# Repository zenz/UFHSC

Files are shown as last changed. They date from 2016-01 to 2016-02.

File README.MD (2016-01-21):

准备开源一个东西，用来控制地暖系统的。
市场上有类似的产品，但都是闭源的，这个开源，爱折腾爱研究爱写程序的，可以通过这个东西来设计和测试自己的地暖控制逻辑。

包含的接口有：
1、两路温度传感器接口（用B=3950，100K 精度1% NTC电阻温度传感器）
2、一路壁挂炉采暖启停控制接口
3、一路循环泵启停控制接口
4、一路负载式温控面板接口
5、一路温控面板直接控制的热电阀接口
6、一个UART通讯接口，用于通过USB2TTL接线实现与电脑串口通讯
7、一个ICSP接口，用于给单片机刷写Bootloader
8、一个ESP-05款无线WIFI模块接口，用于实现IoT监控
9、一个USB/AC供电跳针接口，用于选择单片机电源供给方式，调试用
10、一个预留的开关判断接口（目前在代码中用于是否连接循环泵的判断）

整个设备，全部采用直插式原件，方便爱好者自己焊接制作。所有用到的零件，都可以在网上（淘宝）购买到。
温度传感器精度可通过选择精度高的NTC电阻以及分压电阻(4.7K)来调节。
目前选用的NTC精度1%，分压电阻精度5%，测试下来在测试物温度恒定时，波动温度不超过0.2度（个人认为对地暖来说这个精度够了，波动更大的原因是开关电源的稳定性）。

单片机采用ATMEL公司的ATMEGA328P-PU，8位处理芯片，FLASH内存32K，动态内存2K，刷开源固件Arduino。
原始控制代码也全部开源，用Arduino编写，在Arduino IDE 1.0.5 以上版本编译通过并可通过USB2TTL上传到单片机。

开源的目的是什么？
个人一直是开源（软硬件）的支持者，认同开源可以使得在开放式讨论环境中，目标理论和算法能够得到更充分的探讨和完善。而且能够在使用环境适应性上有更加灵活的应对方法来解决实际的问题。FDM（熔融堆积成型）三维打印机这几年的发展就是一个例子。还有桌面CNC铣床GBRL，微型纺织机FirePicker等等。Github上随便搜搜都能找到一堆的开源软硬件项目。

开源会不会对企业带来经济损失？
个人认为这是一个伪命题。一个企业的研发能力是有限的，特别是中小型企业，要能够有人员和资金持续地，不断投入一个项目的研究还不钻牛角尖是很难的。因此，很多的企业，甚至是大企业，都采取部分开源的做法，来吸引更多对此问题关注的人参与进来，从而在获得的研究结果中提取有利于企业本身的数据和技术，来不断完善企业自己生产和销售的产品。产品做好了，买来使用的人其实占据了绝大多数。

开源需要的是什么？
开源需要的是真诚的交流和主动改变的心态，在这一点上，国外的开发者似乎比国内的做的要好一些。但这几年，国内的开源项目也多起来了。主要还是心态的慢慢转变吧。

接下来会怎么做？
我会把这个项目放到Github上，所有的设计文件，代码，让有想法又愿意分享并贡献的人可以跟进交流。希望这个开源项目能获得更多人的关注，从而使得对地面辐射采暖节能控制更多的了解和应用。这样我就成功了。如果最后也没有什么进步，那么我也至少努力过了。

OK，我要说的说完了。你约不约？

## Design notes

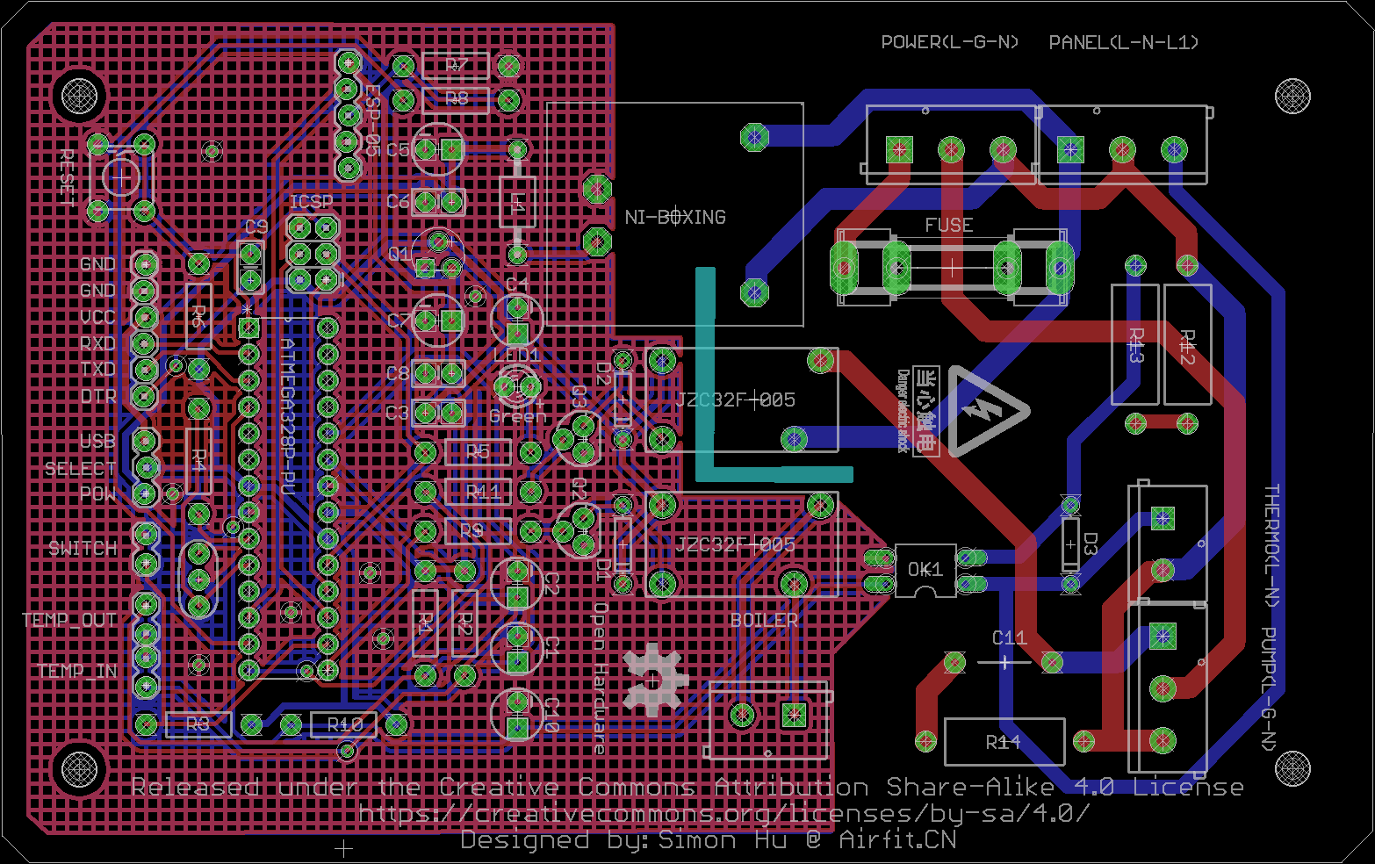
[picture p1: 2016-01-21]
PCB.png

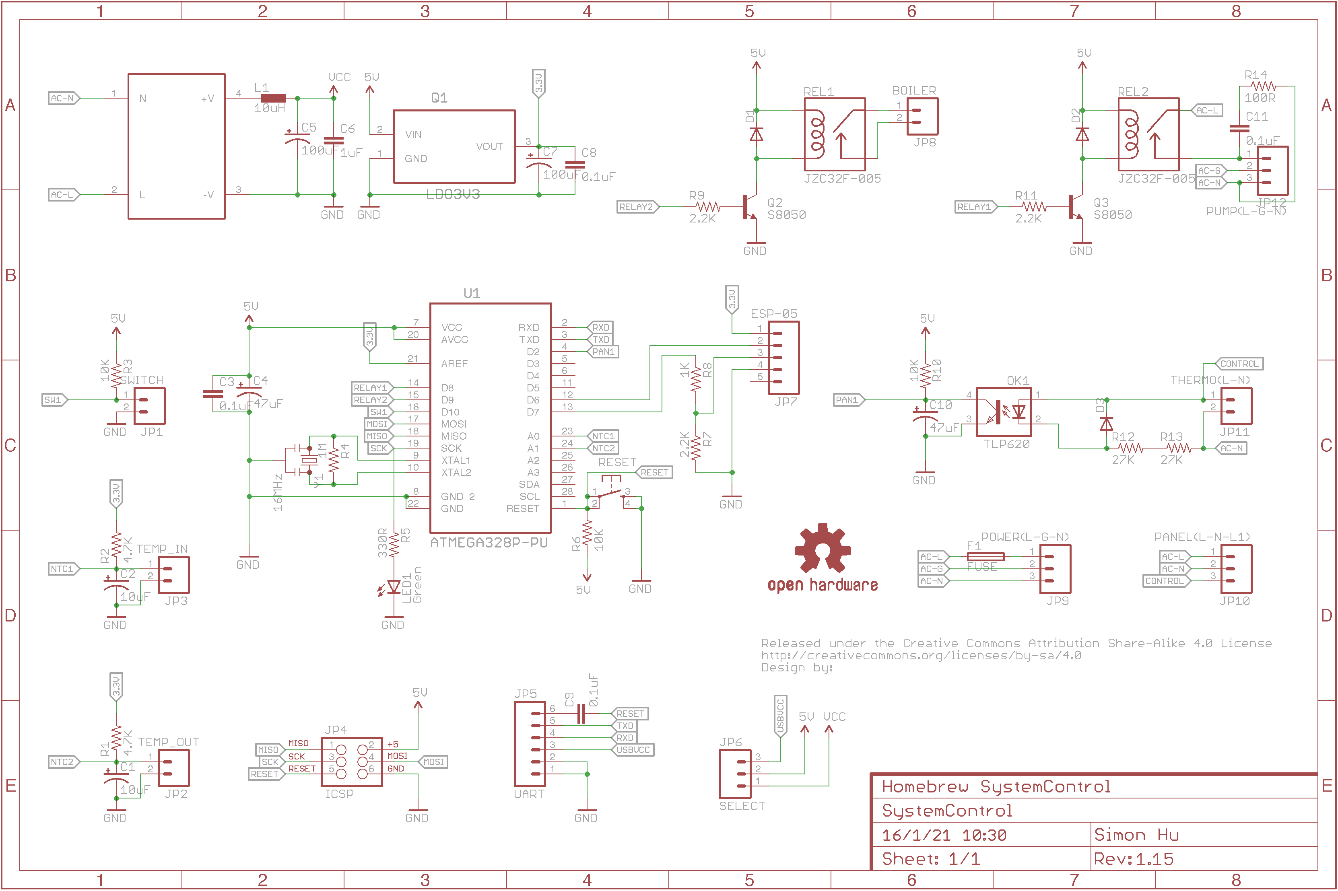
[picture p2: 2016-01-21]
SCH.png

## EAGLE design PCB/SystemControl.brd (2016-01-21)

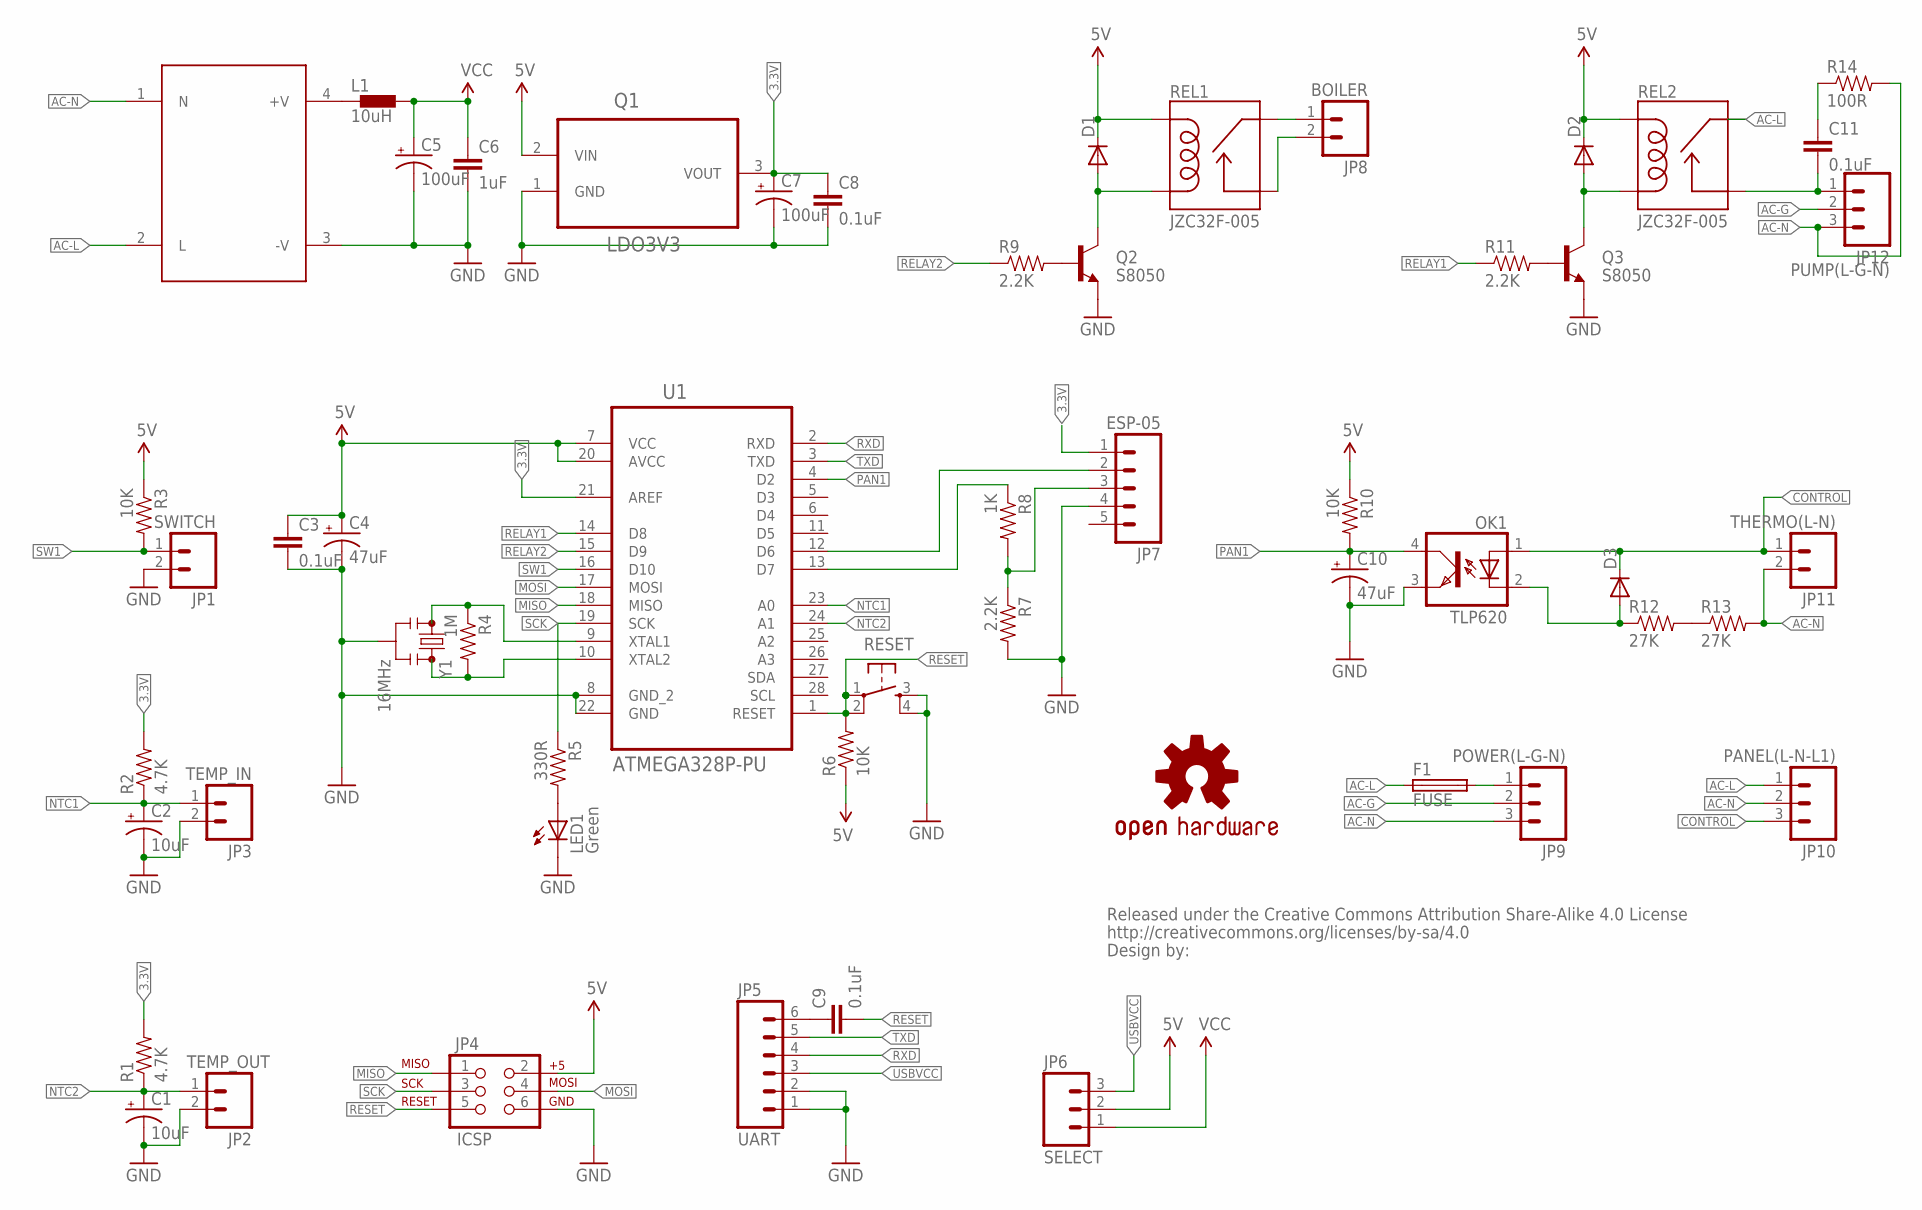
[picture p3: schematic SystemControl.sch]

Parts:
C1, C2: 10uF; CPOL-RADIAL-10UF-25V
C3, C8, C9: 0.1uF; CAP-PTH-SMALL2
C4, C10: 47uF; CPOL-RADIAL-10UF-25V
C5, C7: 100uF; CPOL-RADIAL-10UF-25V
C6: 1uF; CAP-PTH-SMALL2
C11: 0.1uF; CAP-PTH-LARGE
CC_TEXT1: CREATIVE_COMMONS
D1, D2, D3: 1N4007; DO-1N4148
F1: FUSE; SHK20L
IC1: NI-BOXING
JP1: SWITCH; 1X02_LOCK
JP2: TEMP_OUT; 1X02_LOCK
JP3: TEMP_IN; 1X02_LOCK
JP4: ICSP; 2X3
JP5: UART; 1X06_LOCK
JP6: SELECT; 1X03_LOCK
JP7: ESP-05; 1X05_LOCK
JP8: BOILER; SCREWTERMINAL-5MM-2
JP9: POWER(L-G-N); SCREWTERMINAL-5MM-3
JP10: PANEL(L-N-L1); SCREWTERMINAL-5MM-3
JP11: THERMO(L-N); SCREWTERMINAL-5MM-2
JP12: PUMP(L-G-N); SCREWTERMINAL-5MM-3
L1: 10uH; BL01RN1A
LED1: Green; LED3MM
LOGO1: OSHW-LOGOL; OSHW-LOGO-L
OK1: TLP620; DIL04
Q1: LDO3V3; TO127P254X533-3
Q2, Q3: S8050; TO-92
R1, R2: 4.7K; AXIAL-0.4
R3, R6, R10: 10K; AXIAL-0.4
R4: 1M; AXIAL-0.4
R5: 330R; AXIAL-0.4
R7, R9, R11: 2.2K; AXIAL-0.4
R8: 1K; AXIAL-0.4
R12, R13: 27K; AXIAL-0.6
R14: 100R; AXIAL-0.6
REL1, REL2: JZC32F-005; RELAY-JZC
RESET: TAC_SWITCHPTH; TACTILE-PTH
U1: ATMEGA328P-PU; DIP254P762X457-28
Y1: 16MHz; RESONATOR-PTH

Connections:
3.3V: C7.1 (+), C8.1, JP7.1, Q1.3 (VOUT), R1.P$2 (2), R2.P$2 (2), U1.21 (AREF)
5V: C3.1, C4.1 (+), D1.C, D2.C, JP4.2 (VCC), JP6.2, Q1.2 (VIN), R3.P$1 (1), R6.P$1 (1), R10.P$1 (1), REL1.5 (COIL1), REL2.5 (COIL1), U1.7 (VCC), U1.20 (AVCC)
AC-G: JP9.2, JP12.2
AC-L: F1.1A (1), IC1.2 (L), JP10.1, REL2.4 (MAIN)
AC-N: IC1.1 (N), JP9.3, JP10.2, JP11.2, JP12.3, R13.P$2 (2), R14.P$2 (2)
CONTROL: D3.C, JP10.3, JP11.1, OK1.1 (A)
GND: C1.2 (-), C2.2 (-), C3.2, C4.2 (-), C5.2 (-), C6.2, C7.2 (-), C8.2, C10.2 (-), IC1.3 (-V), JP1.2, JP2.2, JP3.2, JP4.6 (GND), JP5.1 (GND), JP5.2 (EMPTY), JP7.4, LED1.K (C), OK1.3 (EMIT), Q1.1 (GND), Q2.1 (E), Q3.1 (E), R7.P$2 (2), RESET.3, RESET.4, U1.8 (GND_2), U1.22 (GND), Y1.2
MISO: JP4.1 (MISO), U1.18 (MISO)
MOSI: JP4.4 (MOSI), U1.17 (MOSI)
unnamed: C9.1, JP5.6 (RESET)
unnamed: R4.P$1 (1), U1.9 (XTAL1), Y1.1
unnamed: R4.P$2 (2), U1.10 (XTAL2), Y1.3
unnamed: Q3.2 (B), R11.P$2 (2)
unnamed: D2.A, Q3.3 (C), REL2.1 (COIL2)
unnamed: Q2.2 (B), R9.P$2 (2)
unnamed: D1.A, Q2.3 (C), REL1.1 (COIL2)
unnamed: JP8.1, REL1.4 (MAIN)
unnamed: JP8.2, REL1.3 (NO)
unnamed: LED1.A, R5.P$2 (2)
unnamed: C11.2, JP12.1, REL2.3 (NO)
unnamed: IC1.4 (+V), L1.1
unnamed: C11.1, R14.P$1 (1)
unnamed: JP7.3, R7.P$1 (1), R8.P$2 (2)
unnamed: F1.2A (2), JP9.1
unnamed: R12.P$2 (2), R13.P$1 (1)
unnamed: D3.A, OK1.2 (C), R12.P$1 (1)
unnamed: JP7.2, U1.12 (D6)
unnamed: R8.P$1 (1), U1.13 (D7)
NTC1: C2.1 (+), JP3.1, R2.P$1 (1), U1.23 (A0)
NTC2: C1.1 (+), JP2.1, R1.P$1 (1), U1.24 (A1)
PAN1: C10.1 (+), OK1.4 (COL), R10.P$2 (2), U1.4 (D2)
RELAY1: R11.P$1 (1), U1.14 (D8)
RELAY2: R9.P$1 (1), U1.15 (D9)
RESET: C9.2, JP4.5 (RESET), R6.P$2 (2), RESET.1, RESET.2, U1.1 (RESET)
RXD: JP5.4 (RXD), U1.2 (RXD)
SCK: JP4.3 (SCK), R5.P$1 (1), U1.19 (SCK)
SW1: JP1.1, R3.P$2 (2), U1.16 (D10)
TXD: JP5.5 (TXD), U1.3 (TXD)
USBVCC: JP5.3 (VCC), JP6.3
VCC: C5.1 (+), C6.1, JP6.1, L1.2

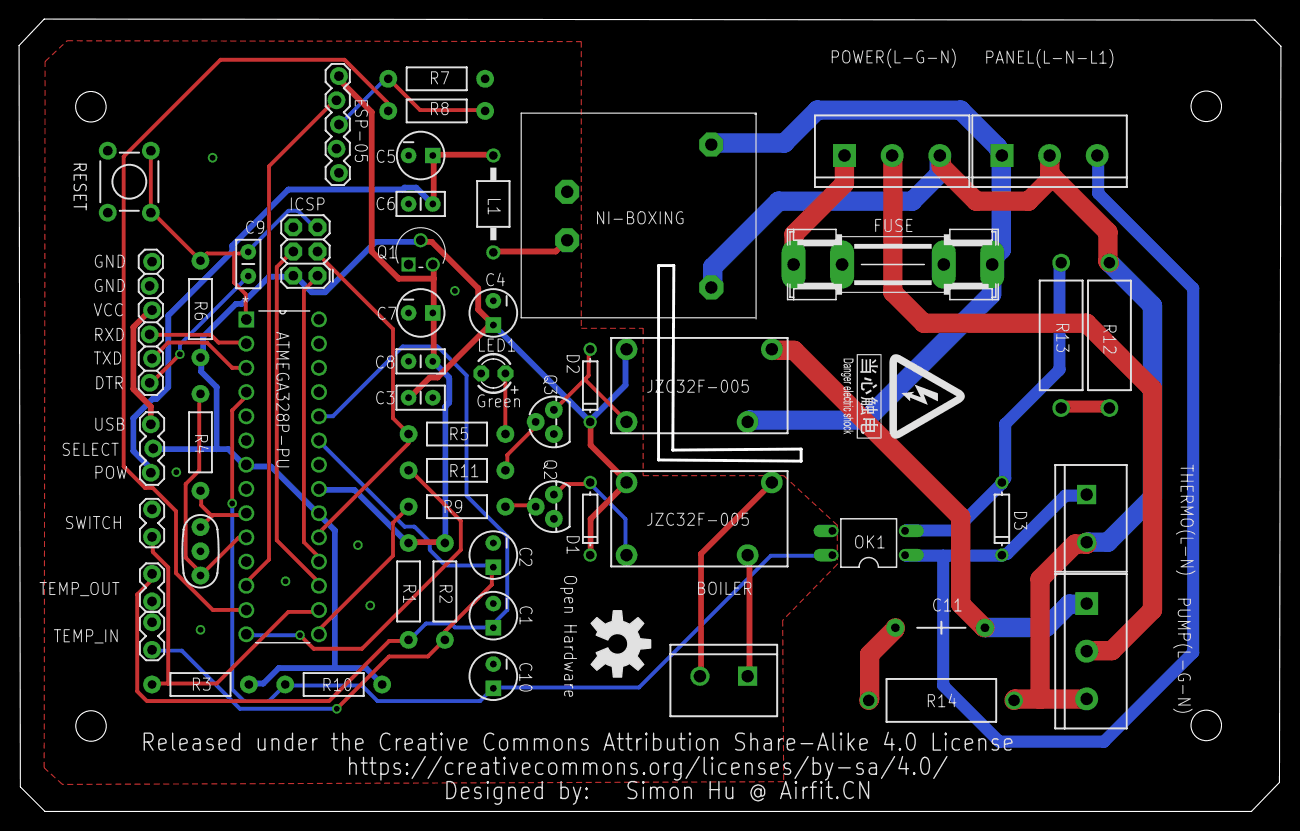
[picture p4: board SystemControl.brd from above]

Board: 2 copper layers, 132.3 x 83.1 mm, 55 parts (0 on the bottom side), 40 nets.

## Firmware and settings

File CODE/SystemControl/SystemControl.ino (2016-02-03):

#include "Boiler.h"
#include "Pump.h"
#include "Panel.h"
#include "Led.h"

#define WORKING_TEMP 30UL // 回水不30度
#define PROTECT_PERIOD 180000UL // 保护时间为3分钟
#define BLINK_INTERVAL_NORMAL 1000UL  // 供热时1秒一闪
#define BLINK_INTERVAL_SHORT 250UL  // 温度出错时1/4秒一闪
#define BLINK_INTERVAL_LONG 3000UL  // 非供热时3秒一闪
#define DISPLAY_INTERVAL 1000UL // 显示间隔1秒
#define UPDATE_INTERVAL 300000UL  // 更新服务间隔5分钟
#define PROCESSING_PLOT // 输出Processing程序监控数据
#define WATCHDOG  // 使用看门狗
//#define DIGITAL_TUBE  // 使用4位数字管
//#define ESPWIFI // 如果开启了ESPWIFI,则会自动关闭PROCESSING_PLOT及WATCHDOG
//#define DEBUG // 允许串口输出调试

#if defined(DIGITAL_TUBE) || defined(ESPWIFI) || defined(PROCESSING_PLOT)
#include "Thread.h"
#include "ThreadController.h"
ThreadController controll = ThreadController();
#endif

#ifdef WATCHDOG
#include <avr/wdt.h>
#endif

#ifdef DIGITAL_TUBE
// 用数字管显示进回水温度
#include "TM1637.h"
#define CLK 11
#define DIO 12
TM1637 tm1637(CLK, DIO);
boolean tmPowerOn = false;
#endif

#if defined(PROCESSING_PLOT) || defined(DIGITAL_TUBE)
Thread* displayThread = new Thread();
#endif

#ifdef ESPWIFI
#undef PROCESSING_PLOT
#undef WATCHDOG
#include "SoftwareSerial.h"
SoftwareSerial Serial1(6, 7); // RX, TX
#include "WiFiEsp.h"

#define ROUTER_SSID "ROUTER" // 路由
#define ROUTER_PASS "PASSWORD" // 密码
#define SERVER "api.yeelink.net"
#define YEELINKAPI  "YOURYEELINKAPI"
#define DEVICEID  344501
#define SENSORID1 382953  // 回水温度
#define SENSORID2 382954  // 进水温度
#define SENSORID3 382955  // 壁挂炉
#define SENSORID4 382956  // 循环泵
#define SENSORID5 382957  // 温控器
int status = WL_IDLE_STATUS;
WiFiEspClient wifiClient;
boolean wifiReady = true;
Thread* updateThread = new Thread();
#endif

// 工作灯
uint8_t pinLed = 13;
// 两个温度传感器
uint8_t pinTempOut = A0, pinTempIn = A1;
// 温控面板
uint8_t pinPanel = 2;
// 壁挂炉采暖控制
uint8_t pinBoiler = 9;
// 循环泵控制
uint8_t pinPump = 8;
uint8_t pinPumpReady = 10;
bool pumpReady;

// 初始化各个类
Led led(pinLed);
Thermistor thermistorIn(pinTempIn);
Thermistor thermistorOut(pinTempOut);
Panel panel(pinPanel);
Boiler boiler;
Pump pump;

// 定义用到的公共变量
uint32_t boilerProtectPeriod, pumpProtectPeriod;
bool panelState = false, boilerState = false, pumpState = false;

//--------------------------------------------------------------------
// 系统初始化
//--------------------------------------------------------------------

void setup() {
#if defined(PROCESSING_PLOT) || defined(ESPWIFI) || defined(DEBUG)
  Serial.begin(9600);
#endif
  analogReference(EXTERNAL);
  pinMode(pinBoiler, OUTPUT); // 输出模式必须显性指定
  pinMode(pinPump, OUTPUT); // 输出模式必须显性指定
  pinMode(pinLed, OUTPUT);

  boiler.setTargetTemperature(WORKING_TEMP);
  boiler.setProtectPeriod(PROTECT_PERIOD);
  pump.setProtectPeriod(PROTECT_PERIOD);
  pumpReady = !digitalRead(pinPumpReady);

#ifdef DIGITAL_TUBE
  tm1637.init(); // 数字管初始化
  tm1637.set(BRIGHT_TYPICAL); // 普通亮度
  tm1637.display(0, 0); // 未进入循环处理程序前,4位全部显示0
  tm1637.display(1, 0);
  tm1637.display(2, 0);
  tm1637.display(3, 0);
#endif

#if defined(DIGITAL_TUBE) || defined(PROCESSING_PLOT)
  displayThread->onRun(displayCallback);
  displayThread->setInterval(DISPLAY_INTERVAL);
  controll.add(displayThread);
#endif

#ifdef ESPWIFI
  // 初始化ESP模块
  Serial1.begin(9600);
  WiFi.init(&Serial1);

  if (WiFi.status() == WL_NO_SHIELD) { // 没有发现ESPwifi模块
    Serial.println("ESP Wifi shield not present");
    wifiReady = false;
  }

  if (wifiReady) {
    while (status != WL_CONNECTED) {
      status = WiFi.begin(ROUTER_SSID, ROUTER_PASS);
    }
    Serial.println("Connected to the network");
    printWifiStatus();
  }

  updateThread->onRun(updateCallback);
  updateThread->setInterval(UPDATE_INTERVAL);
  controll.add(updateThread);
#endif

#ifdef WATCHDOG
  wdt_enable(WDTO_500MS); // 500毫秒无响应视为死机,重新启动. 如果用了Yeelink服务,则应该有更长时间.
#endif
}

//--------------------------------------------------------------------
// 主体循环
//--------------------------------------------------------------------

void loop() {
  panel.update(); // 更新面板状态
  panelState = panel.getState(); // 读取面板状态
  panelState = true; // 测试时强制为导通状态
  if (!panelState) {
    // 如果温控面板关闭了,那么无需壁挂炉启动,泵也应该停止
    led.setBlinkInterval(BLINK_INTERVAL_LONG); // 闪灯频率降到每3秒一次.
    boiler.setTargetTemperature(0);
    boilerState = boiler.update();
    if (pumpReady) { // 有泵,需要进行相应处理
      pump.disable();
      pumpState = pump.update();
    } else {
      pumpState = false;
    }
  } else { // 如果温控面板没有关闭
    led.setBlinkInterval(BLINK_INTERVAL_NORMAL); // 闪灯频率变为1秒一次
    boiler.setTargetTemperature(WORKING_TEMP);
    boilerState = boiler.update();
    if (pumpReady) { // 有泵,需要进行相应处理
      pump.allow();
      pumpState = pump.update();
    } else {
      pumpState = false;
    }
  }
  // 如果温度不正确,闪灯频率变为0.2秒一次
  if (boiler.getTemperatureIn() == -27 || boiler.getTemperatureOut() == -27) {
    led.setBlinkInterval(BLINK_INTERVAL_SHORT);
  }

  led.blink(); // 更新闪灯状态

#if defined(DIGITAL_TUBE) || defined(ESPWIFI) || defined(PROCESSING_PLOT)
  controll.run();
#endif

#ifdef WATCHDOG
  wdt_reset(); // 喂狗,防止重启
#endif
}

//--------------------------------------------------------------------
// 显示功能
//--------------------------------------------------------------------

#if defined(PROCESSING_PLOT) || defined(DIGITAL_TUBE)
void displayCallback() {
#ifdef PROCESSING_PLOT
  Serial.print(boiler.getTemperatureOut());
  Serial.print(",");
  Serial.print(boiler.getTemperatureIn());
  Serial.print(",");
  Serial.print(pumpState);
  Serial.print(",");
  Serial.println(boilerState);
#endif

#ifdef DIGITAL_TUBE
  tm1637.display(0, byte(round(boiler.getTemperatureOut())) / 10);  // 壁挂炉出水温度十位
  tm1637.display(1, byte(round(boiler.getTemperatureOut())) % 10);  // 壁挂炉出水温度个位
  tm1637.display(2, byte(round(boiler.getTemperatureIn())) / 10);   // 壁挂炉回水温度十位
  tm1637.display(3, byte(round(boiler.getTemperatureIn())) % 10);   // 壁挂炉回水温度各位
  tm1637.point(tmPowerOn); // 显示分割符号
  tmPowerOn = !tmPowerOn; // 实现分隔符闪烁
#endif
}
#endif

//--------------------------------------------------------------------
// 网络数据更新功能
//--------------------------------------------------------------------

#ifdef ESPWIFI
void updateCallback() {
  // 面板状态
  Serial.println("update panelState");
  postData(panelState, YEELINKAPI, DEVICEID, SENSORID5);

  // 循环本状态
  Serial.println("update pumpState");
  postData(pumpState, YEELINKAPI, DEVICEID, SENSORID4);

  // 壁挂炉状态
  Serial.println("update boilerState");
  postData(boilerState, YEELINKAPI, DEVICEID, SENSORID3);

  // 出水温度
  Serial.print("Send Output temperature: ");
  Serial.println(boiler.getTemperatureOut());
  postData(round(boiler.getTemperatureOut()), YEELINKAPI, DEVICEID, SENSORID1);

  // 回水温度
  Serial.print("Send Input temperature: ");
  Serial.println(boiler.getTemperatureIn());
  postData(round(boiler.getTemperatureIn()), YEELINKAPI, DEVICEID, SENSORID2);

  Serial.println("Update finished!");
}

void printWifiStatus()
{
  // 显示连接到的SSID
  Serial.print("SSID: ");
  Serial.println(WiFi.SSID());

  // 显示获取的IP地址
  IPAddress ip = WiFi.localIP();
  Serial.print("IP Address: ");
  Serial.println(ip);

  // 显示接受信号强度
  long rssi = WiFi.RSSI();
  Serial.print("Signal strength (RSSI):");
  Serial.print(rssi);
  Serial.println(" dBm");
}

void postData(int data, String apikey, unsigned long deviceid, unsigned long sensorid)
{
  if (wifiClient.connect(SERVER, 80)) {
    Serial.println("Connected to server!");
    Serial.println("Send data now.");
    int thisLength = 10 + getLength(data);

    wifiClient.print("POST /v1.0/device/");
    wifiClient.print(deviceid);
    wifiClient.print("/sensor/");
    wifiClient.print(sensorid);
    wifiClient.print("/datapoints HTTP/1.1\r\nHost: api.yeelink.net\r\n");
    wifiClient.print("Accept: */*\r\nU-ApiKey:");
    wifiClient.print(apikey);
    wifiClient.print("\r\nContent-Length: ");
    wifiClient.print(thisLength);
    wifiClient.print("\r\nContent-Type: application/x-www-form-urlencoded\r\n");
    wifiClient.print("Connection: close\r\n\r\n");
    wifiClient.print("{\"value\":");
    wifiClient.print(data);
    wifiClient.print("}");
    wifiClient.stop();

  } else {
    Serial.println("Connecting failure");
    Serial.println("Send data abort.");
    wifiClient.stop();
  }
}

int getLength(int someValue) {
  int digits = 1;
  int dividend = someValue / 10;

  while (dividend > 0) {
    dividend = dividend / 10;
    digits++;
  }
  return digits;
}
#endif

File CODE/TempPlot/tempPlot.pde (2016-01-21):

import processing.serial.*;

PFont f;
PFont F;
Serial myPort;        // The serial port
int xPos = 40;         // horizontal position of the graph

void setup () {
  // set the window size:  and Font size
  f = createFont("Arial", 12, true);
  F = createFont("Arial", 24, true);
  size(1024, 600);

  // List all the available serial ports
  //println(Serial.list());
  myPort = new Serial(this, "/dev/tty.SLAB_USBtoUART", 9600);
  myPort.bufferUntil('\n');
  // set inital background:
  background(100);
}
void draw () 
{
  String inputString, inString, outString, pumpString, boilerString;
  // everything happens in the serialEvent()
  if (myPort.available()>0) {
    // get the ASCII string:
    inputString = myPort.readStringUntil('\n');
    inString ="";
    if (inputString != null) {
      // trim off any whitespace:
      String[] temp = splitTokens(inputString, ",");
      print("State: ");
      print(inputString);
      if (temp[0] !=null) {
        outString = trim(temp[0]);
      } else {
        outString = "0";
      }
      if (temp[1] !=null) {
        inString = trim(temp[1]);
      } else {
        inString = "0";
      }
      if (temp[2] !=null) {
        pumpString = trim(temp[2]);
      } else {
        pumpString = "0";
      }
      if (temp[3] !=null) {
        boilerString = trim(temp[3]);
      } else {
        boilerString = "0";
      }

      // convert to an int and map to the screen height:
      float inByte = float(inString+(char)9); 
      inByte = map(inByte, 0, 117, 0, height);

      float outByte = float(outString+(char)9);
      outByte = map(outByte, 0, 117, 0, height);

      //println(inByte);

      stroke(175);                       // temperature line
      fill(150);
      line(40, height-40, 40, 0);

      stroke(175);                          // Time line
      line(40, height-40, width, height-40);

      stroke(100, 100, 255);                          // 30 degree line
      line(40, height-194, width, height-194);

      stroke(100, 100, 255);                          // 60 degree line
      line(40, height-344, width, height-344);

      textFont(F);       
      fill(255);

      textAlign(RIGHT);
      text("Temperature Ploting Programme", width-100, 40); 

      textAlign(RIGHT);
      text("By SimonHu@Airfit.CN", width-100, 70); 

      textAlign(RIGHT);
      text("Temp", 70, 40);                         

      textAlign(RIGHT);
      text("Time --->", width-50, 580);    

      fill(0);
      // int j;
      stroke(255);   
      for (int j=width-100; j>width-510; j--) //260
      {
        line(j, 80, j, 107);
      }
      stroke(0, 0, 0);
      textAlign(RIGHT);
      text("S:"+outString +", R:" + inString, width-110, 102); 
      // draw pumpState
      text("PUMP:"+pumpString, width-410, 102);
      // draw boilerState
      text("BOILER:"+boilerString, width-295, 102);


      fill(240);
      textFont(f); 

      textAlign(RIGHT);
      text("(In Degree)", 140, 40); 

      textAlign(RIGHT);                 // 100 degree
      text("100 -", 40, 60);

      textAlign(RIGHT);                // 90 degree
      text("90 -", 40, 110);

      textAlign(RIGHT);                // 80 degree
      text("80 -", 40, 160);

      textAlign(RIGHT);                 // 70 degree
      text("70 -", 40, 210);

      textAlign(RIGHT);                // 60 degree
      text("60 -", 40, 260);

      textAlign(RIGHT);               // 50 degree
      text("50 -", 40, 310);

      textAlign(RIGHT);                 // 40 degree
      text("40 -", 40, 360);

      textAlign(RIGHT);
      text("30 -", 40, 410);

      textAlign(RIGHT);
      text("20 -", 40, 460);

      textAlign(RIGHT);
      text("10 -", 40, 510);

      textAlign(RIGHT);
      text("0 -", 40, 560);

      /*---- scale between 30 degree to 40 degree------*/

      textAlign(RIGHT);
      text("   -", 40, 370);

      textAlign(RIGHT);
      text("   -", 40, 380);

      textAlign(RIGHT);
      text("   -", 40, 390);

      textAlign(RIGHT);
      text("   -", 40, 400);

      // draw the line:
      int shift=40;            // set trace origin
      stroke(0, 255, 0);              // trace colour
      for (int i=0; i<2; i++)
      {
        //line(xPos, height-inByte-1, xPos, height - inByte);
        line(xPos, height-inByte-(shift+3), xPos, height-inByte-shift);
        xPos++;
      }

      // draw out temp
      stroke(255, 0, 0);              // trace colour
      for (int i=0; i<2; i++)
      {
        //line(xPos, height-inByte-1, xPos, height - inByte);
        line(xPos, height-outByte-(shift+3), xPos, height-outByte-shift);
        xPos++;
      }
      if (xPos >= width)         //  go back to begining
      {
        xPos = 40;
        background(100);
      }
    }
  }
}

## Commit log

2016-01-21 add a processing program to demo simple temperature ploting
2016-02-01 WiFi, 伪PID，伪线程
2016-02-03 修正显示编译选项的BUG

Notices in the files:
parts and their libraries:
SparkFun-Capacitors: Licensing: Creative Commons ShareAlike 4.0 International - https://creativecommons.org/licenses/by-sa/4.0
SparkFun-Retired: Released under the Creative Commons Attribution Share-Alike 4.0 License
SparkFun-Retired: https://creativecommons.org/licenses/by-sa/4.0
